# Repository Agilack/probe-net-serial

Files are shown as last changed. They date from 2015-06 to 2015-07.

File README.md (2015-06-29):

# probe-net-serial
Ethernet to serial adapter. Allow remote control of a serial port (remote console, debug port, ...) 

 * hw-netserial-r01: Hardware board

 * sw-bootloader: Allow flash/update using DHCP and TFTP (if SW0 is pushed on startup)

 * sw-unit_tests: Some unit-tests for software and hardware

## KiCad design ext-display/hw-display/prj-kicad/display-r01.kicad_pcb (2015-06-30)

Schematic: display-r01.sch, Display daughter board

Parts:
C101, C102, C109, C110: 1uF
C103, C105: 10uF
C106, C108: 4,7uF
C107: 2,2uF
C111: C
DISP1: ER-OLED0.91-1
DISP2: ER-OLED0.91-3
L101: 4.7uH
MISO1: CONN_1
P1, P2, P3: CONN_1
PP1, PP2: CONN_1
R101, R102: R
R103: 560k
TP101, TP102, TP103: CONN_1
U1: EFM8BB10F8G-A-SOIC16
U2: TLV61220

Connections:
+3.3V: C105.1, DISP1.7 (VDD), DISP2.7 (VDD), L101.1, P1.1, U1.5, U2.3 (EN), U2.6 (VBAT)
DISP_DC: DISP1.10 (D/C), DISP2.10 (D/C), U1.11 (P1.0)
DISP_RST: DISP1.9 (RES), DISP2.9 (RES), U1.10 (P1.1)
GND: C103.2, C105.2, C106.2, C107.2, C108.2, C111.2, DISP1.6, DISP2.6, P2.1, R102.2, R103.2, U1.4, U2.2
IREF: DISP1.13 (IREF), DISP2.13 (IREF), R103.1
unnamed: R101.2, R102.1, U2.4 (FB)
unnamed: MISO1.1, U1.2 (P0.1)
unnamed: TP101.1, U1.15 (P0.4)
unnamed: C101.2, DISP1.4 (C1N)
unnamed: C111.1, DISP2.14 (VCOMH)
unnamed: C108.1, DISP2.15 (VCC)
unnamed: C101.1, DISP1.3 (C1P)
unnamed: C102.1, DISP1.1 (C2P)
unnamed: C102.2, DISP1.2 (C2N)
unnamed: L101.2, U2.1 (SW)
unnamed: PP1.1, U1.7 (P2.0)
unnamed: PP2.1, U1.6 (RST)
unnamed: C106.1, DISP1.15 (VCC)
unnamed: C107.1, DISP1.14 (VCOMH)
unnamed: C110.1, DISP2.1 (C2P)
unnamed: TP102.1, U1.13 (P0.6)
unnamed: TP103.1, U1.12 (P0.7)
unnamed: C109.2, DISP2.4 (C1N)
unnamed: C109.1, DISP2.3 (C1P)
unnamed: C110.2, DISP2.2 (C2N)
SPI_CS: DISP1.8 (CS), DISP2.8 (CS), U1.16 (P0.3)
SPI_MOSI: DISP1.12 (SDIN), DISP2.12 (SDIN), U1.1 (P0.2)
SPI_SCK: DISP1.11 (SCLK), DISP2.11 (SCLK), U1.3 (P0.0)
UART_RX: P3.1, U1.14 (P0.5)

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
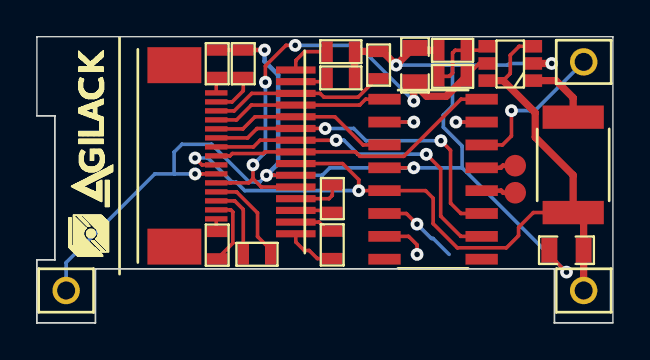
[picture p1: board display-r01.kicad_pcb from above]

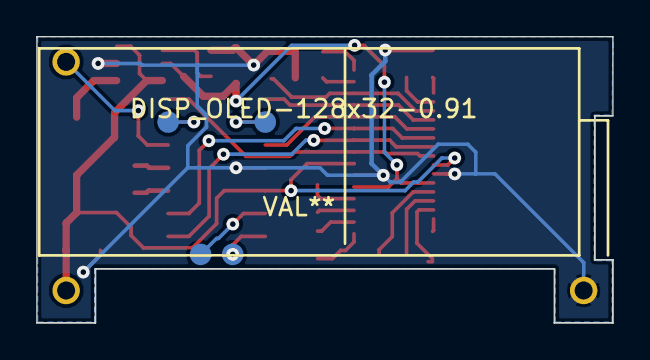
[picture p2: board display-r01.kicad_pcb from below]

Board: 2 copper layers, 32.0 x 15.9 mm, 29 parts (5 on the bottom side), 30 nets.

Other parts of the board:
DISP_OLED-128x32-0.91: VAL**; DISP_OLED-128x32-0.91-1-rev
agilack-11.5: 450px; agilack-11.5

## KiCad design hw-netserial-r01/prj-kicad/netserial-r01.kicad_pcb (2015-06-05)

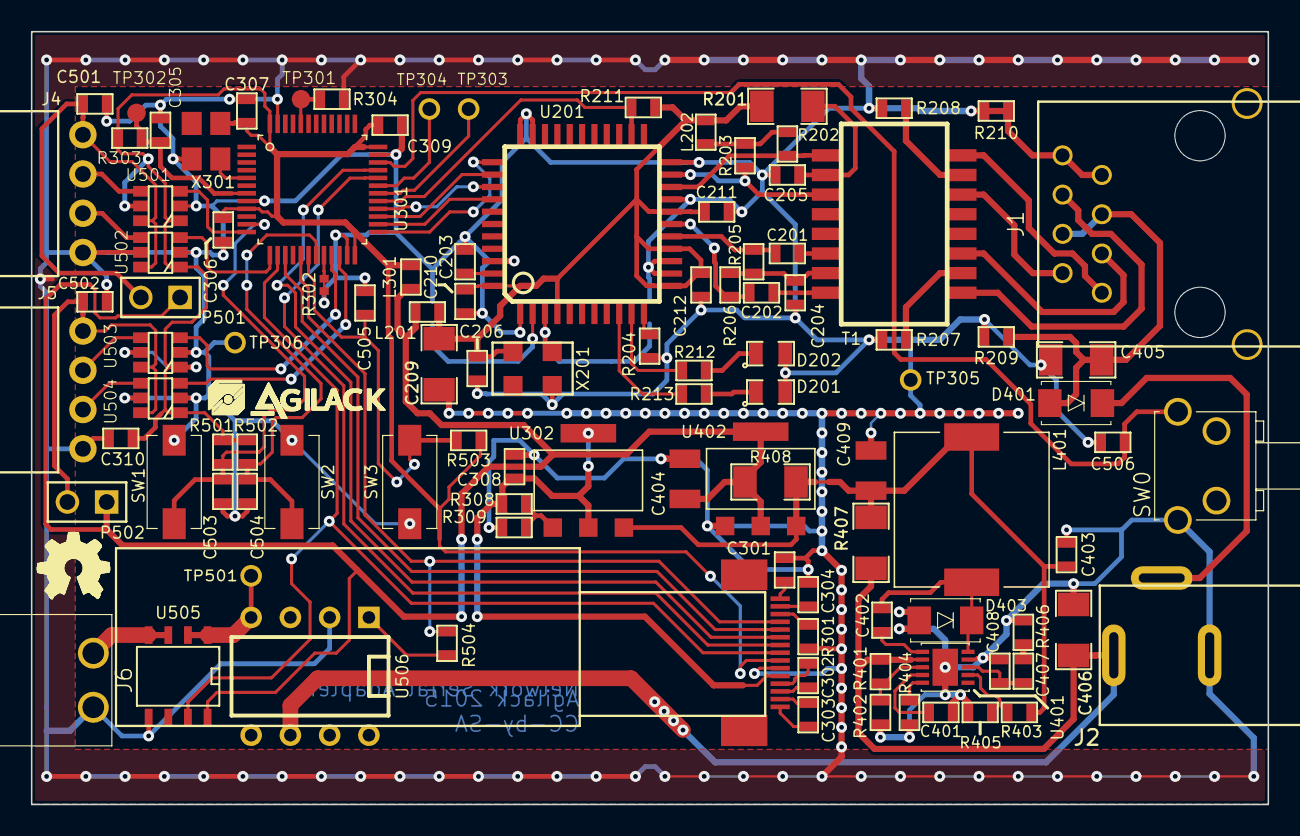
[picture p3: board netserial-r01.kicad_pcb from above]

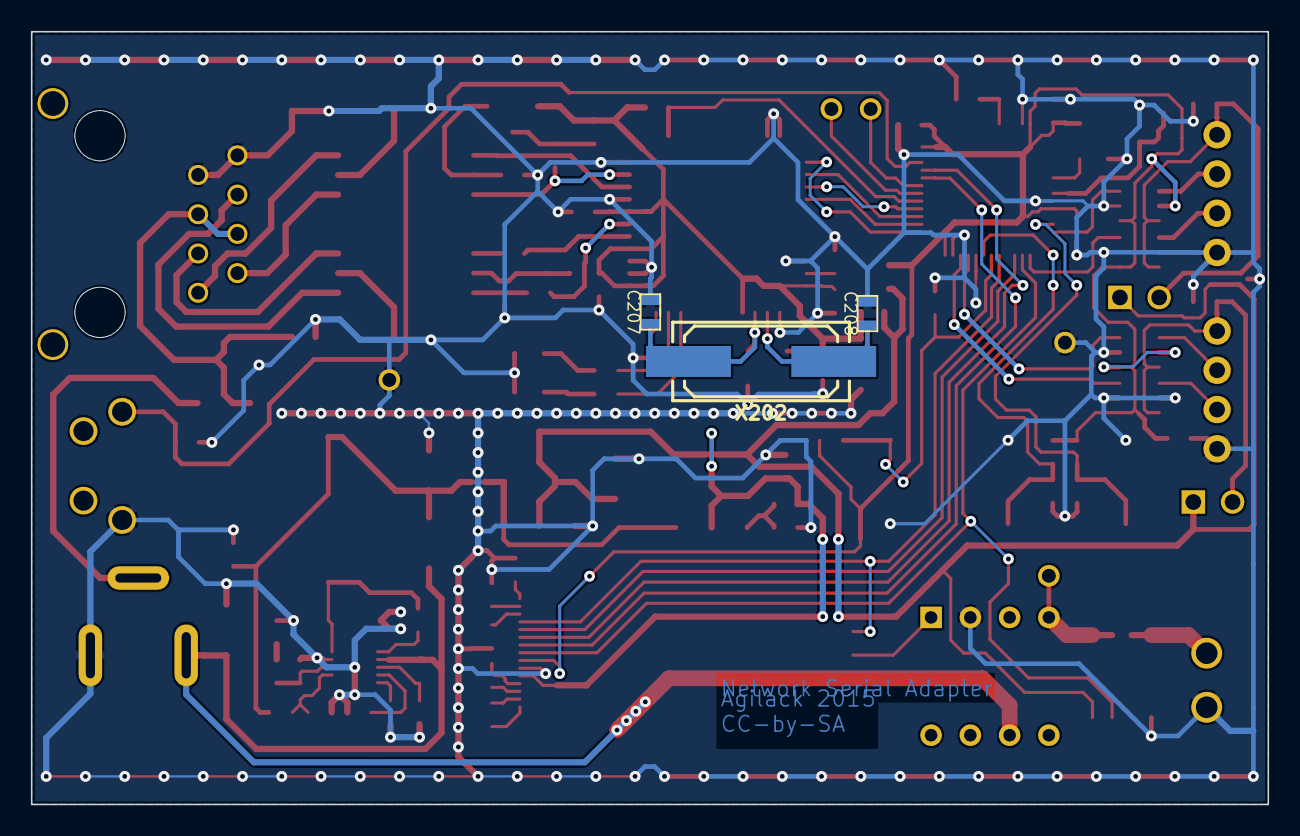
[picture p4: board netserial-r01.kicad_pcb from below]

Board: 2 copper layers, 80.0 x 50.0 mm, 113 parts (3 on the bottom side), 80 nets.

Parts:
C201, C202: 68nF; SMD0603
C203, C308: 10uF; SMD0603
C204, C205, C401: 10nF; SMD0603
C206, C210, C211, C212, C305, C306, C307, C309, C310, C501, C502, C503, C504, C505, C506: C; SMD0603
C207, C208: 18pF; SMD0603
C209: 2,2uF; SMD1206
C301: 4,7uF; SMD0603
C302, C303, C403: 1uF; SMD0603
C304: 2,2uF; SMD0603
C402: 100nF; SMD0603
C404, C409: 47uF; C_TAJB
C405, C406: 10uF; SMD1206
C407: 180pF; SMD0603
C408: 10Pf; SMD0603
D201, D202: LED; SMD0805p
D401: S1D; DO214-AC
D403: B160; DO214-AC
DISP1: ER-OLED0.91-3; CONN_ER-CON15HT-1
DISP_OLED-128x32-0.91: VAL**; DISP_OLED-128x32-0.91
J1: CONN_RJ45; CONN_615008140121
J2: DC10A-2.1; CONN_DC-10
J4, J5: CONN_4; CONN_BG302-04
J6: CONN_2; CONN_691322110002
L201: INDUCTOR; SMD0603
L202, L301: FB100; SMD0603
L401: 47uH; I_MSS1048
P501, P502: JUMPER; CONN_2
R201: 10; SMD1206
R202, R203, R205, R206: 49.9; SMD0603
R204: 12.4k; SMD0603
R207, R208, R209: 75; SMD0603
R210, R308, R309, R403, R405, R504: R; SMD0603
R211, R401, R404: 100k; SMD0603
R212, R213: 330; SMD0603
R301: 560k; SMD0603
R302: 0; SMD0402
R303, R304, R501, R502, R503: 10k; SMD0603
R402: 48.7k; SMD0603
R406: 75K; SMD0603
R407, R408: 0; SMD1206
SW0: SW_PUSH; SW_SKHHLRA010
SW1, SW2, SW3: SW_PUSH; SW_434123043816
T1: TRANSFORMER_1:1; TR_W749013011
TP301, TP302: CONN_1; TP_SMD
TP303, TP304, TP305, TP306, TP501: CONN_1; TP_PIN
U201: ENC424J600; TQFP44
U301: STM32F103CX; LQFP48
U302: LDO_1117-ADJ; SOT223
U401: TPS54060; SMD_SON10
U402: LDO_1117-3.3; SOT223
U501, U502, U503, U504: SN74LVC1T45; SOT23-6
U505: ACS711; SMD_SO8E
U506: VO14642AT; DIP-8__300
X201: 25MHz; Q_HC536
X202: 25MHz; Q_49U3HMS
X301: 7.3728MHz; Q_3.2x2.5
agilack-11.5: 450px; agilack-11.5
ohw_logo: VAL**; ohw-logo

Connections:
+3.3V: C404.1, L201.1, L301.1, P501.1, P502.1, R408.2, U402.2, U402.4, U505.8
+5V: C403.1, C409.1, L401.2, R403.1, R407.2, R408.1, U302.3, U402.3
+Vcpu: C306.1, C307.1, C309.1, C310.1, DISP1.7, L301.2, R303.1, R501.1, R502.1, R503.1, U301.9, U301.24, U301.36, U301.48, U501.1, U501.5, U502.1, U503.1, U503.5, U504.1, X301.4
+Veth: C206.1, C209.1, C210.1, C211.1, C212.1, L201.2, L202.2, R201.1, R211.1, U201.4, U201.12, U201.15, U201.18, U201.44, X201.4
+Vin: C406.1, J2.2, R401.1, R407.1, U401.2, U506.6
+Vpoe: C405.1, D401.1, J1.4, J1.5, R209.2
+Vport1: C501.1, J4.4, P501.2, U501.6, U502.6
+Vport2: C502.1, J5.4, P502.2, U503.6, U504.6
Boot0: R304.1, TP301.1, U301.44
DISP_CD: DISP1.10, U301.33
DISP_RST: DISP1.9, U301.32
ETH_IT: R211.2, U201.24, U301.29
GND: C203.2, C204.2, C205.2, C206.2, C207.2, C208.2, C209.2, C210.2, C211.2, C212.2, C301.2, C304.2, C305.2, C306.2, C307.2, C308.2, C309.2, C310.2, C401.2, C403.2, C404.2, C405.2, C406.2, C408.2, C409.2, C501.2, C502.2, C503.2, C504.2, C505.2, C506.2, D201.2, D202.2, D403.1, DISP1.6, J1.7, J1.8, J2.1, J4.1, J5.1, J6.2, R204.2, R207.1, R208.2, R209.1, R210.1, R210.2, R301.2, R302.1, R302.2, R304.2, R309.2, R402.2, R404.2, R405.2, R406.2, SW0.1, SW1.1, SW2.1, SW3.1, TP305.1, TP306.1, U201.1, U201.13, U201.14, U201.19, U201.22, U201.32, U201.33, U201.42, U301.8, U301.20, U301.23, U301.35, U301.47, U401.9, U401.PAD, U402.1, U501.2, U502.2, U502.5, U503.2, U504.2, U504.5, U505.5, U506.2, X201.2, X301.2
unnamed: C207.1, U201.3, X201.3, X202.1
unnamed: C208.1, U201.2, X202.2
unnamed: R213.2, U201.9
unnamed: R212.1, U201.10
unnamed: D201.1, R213.1
unnamed: D202.1, R212.2
unnamed: R208.1, T1.15
unnamed: J1.2, T1.14
unnamed: J1.1, T1.16
unnamed: J1.3, T1.11
unnamed: J1.6, T1.9
unnamed: C201.2, T1.6
unnamed: R207.2, T1.10
unnamed: C202.2, T1.8
unnamed: R202.1, T1.1, U201.20
unnamed: C203.1, U201.43
unnamed: R204.1, U201.11
unnamed: R203.2, T1.3, U201.21
unnamed: L202.1, R202.2, R203.1
unnamed: C205.1, R201.2, T1.2
unnamed: C204.1, R205.1, R206.2, T1.7
unnamed: C201.1, R205.2, U201.16
unnamed: C202.1, R206.1, U201.17
unnamed: C308.1, DISP1.5, R308.1, U302.2, U302.4
unnamed: R308.2, R309.1, U302.1
unnamed: U301.5, X301.3
unnamed: C303.1, DISP1.1
unnamed: C304.1, DISP1.14
unnamed: C303.2, DISP1.2
unnamed: C302.2, DISP1.4
unnamed: C302.1, DISP1.3
unnamed: C301.1, DISP1.15
unnamed: DISP1.13, R301.1
unnamed: R403.2, R405.1, U401.7
unnamed: C407.1, C408.1, U401.8
unnamed: C407.2, R406.1
unnamed: C402.1, U401.1
unnamed: R401.2, R402.1, U401.3
unnamed: C402.2, D403.2, L401.1, U401.10
unnamed: C401.1, U401.4
unnamed: R404.1, U401.5
unnamed: D401.2, J2.3
unnamed: R504.2, U506.1
unnamed: J6.1, U505.3, U505.4
unnamed: TP501.1, U505.1, U505.2, U506.4
unnamed: J4.3, U501.4
unnamed: J5.3, U503.4
unnamed: J4.2, U502.4
unnamed: J5.2, U504.4
PWR_SENSE: DISP1.8, U301.14, U505.7
Reset: C305.1, R303.2, TP302.1, U301.7
SPI1_MOSI: DISP1.12, R504.1, U301.17
SPI1_SCK: DISP1.11, U301.15
SPI2_MISO: U201.35, U301.27
SPI2_MOSI: U201.36, U301.28
SPI2_NSS: U201.34, U301.25
SPI2_SCK: U201.37, U301.26
SW0: C506.1, SW0.2, U301.34
SW1: C503.1, R501.2, SW1.2, U301.11
SW2: C504.1, R502.2, SW2.2, U301.19
SW3: C505.1, R503.2, SW3.2, U301.18
UART2_RX: U301.13, U502.3
UART2_TX: U301.12, U501.3
UART3_RX: U301.22, U504.3
UART3_TX: U301.21, U503.3
UART_RX: TP304.1, U301.31
UART_TX: TP303.1, U301.30

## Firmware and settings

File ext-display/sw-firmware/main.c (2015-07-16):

/**
 * NetSerial Display Extention - Character firmware
 *
 * Copyright (c) 2015 Saint-Genest Gwenael <gwen@agilack.fr>
 *
 * This file may be distributed and/or modified under the terms of the
 * GNU General Public License version 2 as published by the Free Software
 * Foundation. (See COPYING.GPL for details.)
 *
 * This file is provided AS IS with NO WARRANTY OF ANY KIND, INCLUDING THE
 * WARRANTY OF DESIGN, MERCHANTABILITY AND FITNESS FOR A PARTICULAR PURPOSE.
 */
#include <efm8bb1.h>
#include "hardware.h"
#include "spi.h"
#include "display.h"

static u8 h2b(u8 c);

int main (void)
{
	u8  c;
	u8  nibble;
	int state;
	
	hw_init();

	disp_init();

#ifdef USE_SPLASH
	disp_splash();
#else
	disp_clear();
#endif

	SCON0_RI = 0;
	state = 0;
	nibble = 0;
	P0_6;
	
	while (1)
	{
		/* If the UART Receive Interrupt Flag is set */
		if (SCON0_RI)
		{
			P0_6 = 1;
			/* Read the received byte */
			c = SBUF0;
			/* Clear the RI flag */
			SCON0_RI = 0;
			
			if ((c == '\r') || (c == '\n'))
			{
				if (state > 1)
					disp_line(0);
				state = 0;
				P0_6 = 0;
				continue;
			}
			if (state == 0)
			{
				state = 1;
				if ((c >= '0') && (c <= '3'))
				{
					disp_line(c - '0');
					P0_6 = 0;
					continue;
				}
				if (c == '8')
				{
					state = 2;
					disp_draw_front(1);
					P0_6 = 0;
					continue;
				}
				if (c == '9')
				{
					state = 0;
					disp_draw_front(0);
					P0_6 = 0;
					continue;
				}
				if (c == 0x1B)
				{
					disp_clear();
					state = 0;
					P0_6 = 0;
					continue;
				}
				state = 99;
				continue;
			}
			if (state == 2)
			{
				nibble = h2b(c) << 4;
				state = 3;
			}
			else if (state == 3)
			{
				nibble |= h2b(c);
				disp_wr(nibble);
				state = 2;
			}
			else if (state == 1)
			{
				/* Send the byte to character generator */
				disp_putc(c);
			}
			P0_6 = 0;
		}
	}
}

static u8 h2b(u8 c)
{
	if ((c >= '0') && (c <= '9'))
		return (c - '0');
	if ((c >= 'a') && (c <= 'f'))
		return (c - 'a' + 10);
	if ((c >= 'A') && (c <= 'A'))
		return (c - 'A' + 10);
	
	return(0);
}

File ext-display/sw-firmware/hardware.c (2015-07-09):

/**
 * NetSerial Display Extention - Character firmware
 *
 * Copyright (c) 2015 Saint-Genest Gwenael <gwen@agilack.fr>
 *
 * This file may be distributed and/or modified under the terms of the
 * GNU General Public License version 2 as published by the Free Software
 * Foundation. (See COPYING.GPL for details.)
 *
 * This file is provided AS IS with NO WARRANTY OF ANY KIND, INCLUDING THE
 * WARRANTY OF DESIGN, MERCHANTABILITY AND FITNESS FOR A PARTICULAR PURPOSE.
 */
#include <efm8bb1.h>
#include <efm8bb1_defs.h>
#include "hardware.h"

void hw_init(void)
{
	// Disable Watchdog
	WDTCN = 0xDE; // First key
	WDTCN = 0xAD; // Second key
	
	// Configure port 0
	P0MDOUT = P0MDOUT_B0__PUSH_PULL | P0MDOUT_B1__OPEN_DRAIN | P0MDOUT_B2__PUSH_PULL
		 | P0MDOUT_B3__PUSH_PULL | P0MDOUT_B4__PUSH_PULL | P0MDOUT_B5__OPEN_DRAIN
		 | P0MDOUT_B6__PUSH_PULL | P0MDOUT_B7__PUSH_PULL;
        // Set default values to debug test-points
        P0_6 = 0;
        P0_7 = 0;
        
	// Configure port 1
	P1MDOUT = P1MDOUT_B0__PUSH_PULL | P1MDOUT_B1__PUSH_PULL | P1MDOUT_B2__OPEN_DRAIN
		 | P1MDOUT_B3__OPEN_DRAIN;

	// Configure crossbar
	XBR0 = XBR0_URT0E__ENABLED | XBR0_SPI0E__ENABLED | XBR0_SMB0E__DISABLED
		 | XBR0_CP0E__DISABLED | XBR0_CP0AE__DISABLED | XBR0_CP1E__DISABLED
		 | XBR0_CP1AE__DISABLED | XBR0_SYSCKE__DISABLED;
	XBR2 = XBR2_WEAKPUD__PULL_UPS_ENABLED | XBR2_XBARE__ENABLED;

	// Configure clocks
	CLKSEL = CLKSEL_CLKSL__HFOSC | CLKSEL_CLKDIV__SYSCLK_DIV_2;
	
	hw_init_timers();
	
	hw_init_spi();
	hw_init_uart();
}

void hw_init_timers(void)
{
	unsigned char TCON_save;
	
	TCON_save = TCON;
	TCON &= ~TCON_TR0__BMASK & ~TCON_TR1__BMASK;
	TH1 = (0xCB << TH1_TH1__SHIFT);
	TCON |= (TCON_save & TCON_TR0__BMASK) | (TCON_save & TCON_TR1__BMASK);

	CKCON0 = CKCON0_SCA__SYSCLK_DIV_4 | CKCON0_T0M__PRESCALE | CKCON0_T2MH__EXTERNAL_CLOCK
		 | CKCON0_T2ML__EXTERNAL_CLOCK | CKCON0_T3MH__EXTERNAL_CLOCK | CKCON0_T3ML__EXTERNAL_CLOCK
		 | CKCON0_T1M__SYSCLK;
	TMOD = TMOD_T0M__MODE0 | TMOD_T1M__MODE2 | TMOD_CT0__TIMER | TMOD_GATE0__DISABLED
		 | TMOD_CT1__TIMER | TMOD_GATE1__DISABLED;
	TCON |= TCON_TR1__RUN;
}

void hw_init_spi(void)
{
	SPI0CKR = (0x00 << SPI0CKR_SPI0CKR__SHIFT);
	SPI0CFG |= SPI0CFG_MSTEN__MASTER_ENABLED;
	SPI0CN0 |= SPI0CN0_SPIEN__ENABLED | SPI0CN0_NSSMD__4_WIRE_MASTER_NSS_HIGH;
}

void hw_init_uart(void)
{
	SCON0 |= SCON0_REN__RECEIVE_ENABLED;
}

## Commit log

2015-03-25 = UPD: Fix ethernet ut bug when TX is used without hardware interrupt
    [eth.c, hardware.c, main.c]
2015-04-23 = UPD: Improve loader/firmware integration - Start external oscillator and PLL before calling firmware - Add API vectors entry - uart functions
    [hardware.c, hardware.h, main.c]
2015-05-27 = UPD: Optimize SPI functions - Remove function pointers (reduce code size, and increase speed) - Update ethernet ENC driver
2015-05-28 = UPD: Fix ethernet issues - Fix ARP init bug (bad cache index) - Init MAC address on init, and move it from ip to eth layer - Remove old/unused dhcp callback
    [dhcp.c, eth.c, ip_arp.c]
2015-05-29 = UPD: Improve boot - Test if the firmware image is valid before jumping to it - Relocate vectors to allow firmware to get interrupts - Use systick instead of timer2
2015-06-01 = UPD: Improve network layer - Remove fixed rx/tx buffers and create dynamic position functions - Add an extensible protocol support to allow, for example TCP suport into fw - Reduce the needed RAM t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
    [eth.c, main.c]
2015-06-01 = FIX: Improve IP datagram - Compute ip length into ip_tx() - Fix fragment offset bug (sometimes uninitialized) - Add network function to API / link space
    [dhcp.c, tftp.c]
2015-06-03 = ADD: Unit test for UART2 and UART3
2015-06-03 = UPD: Add DMA support - Create uartX_putm functions to send datas using DMA - Init channels and buffers for RX - Add a generic memory-to-memory copy function
2015-06-04 = UPD: Improve ethernet TX - Change SPI prescaler -> clk/2 - Use one WCRU transaction instead of 4 WCR to set TX addr and TX len - Use dedicated SBI to start TX - Remove bank sel when SFR are availab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
2015-06-05 = ADD: First revision of the netserial PCB board
    [netserial-r01-cpu.sch, netserial-r01-io.sch, netserial-r01-net.sch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]
2015-06-09 = ADD: Gerber and production files for netserial PCB
    [netserial-r01-B_Cu.gbl, netserial-r01-B_Mask.gbs, netserial-r01-B_SilkS.gbo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]
2015-06-30 = ADD: Create extension board for display
    [display-r01.kicad_pcb, display-r01.sch]
2015-07-01 = ADD: Generate production files for display extension board
    [display-r01-B_Cu.gbl, display-r01-B_Mask.gbs, display-r01-B_Paste.gbp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]
2015-07-07 = ADD: Software unit-tests for display extension - UT UART
2015-07-08 = FIX: change UART speed to improve 115200 communication
    [hardware.c, main.c]
2015-07-09 = UPD: Improve character generator (increase SPI speed and reduce CS time lost)
2015-07-12 = UPD: Add a display function to select the current line (0 to 3)

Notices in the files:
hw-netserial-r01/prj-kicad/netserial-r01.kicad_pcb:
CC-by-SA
